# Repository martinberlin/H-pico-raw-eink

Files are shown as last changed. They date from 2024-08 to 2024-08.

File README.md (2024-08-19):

# H-pico-raw-eink

This is just a prototype PCB to test parallel eink signals with Raspberry PICO.

## Important To-Dos:

Find out if the pins selected for P-Mic signals and EINK signals behave correctly and are capable to do the job.

## Relevant datasheets

High voltages required by EPD P-Mic

https://www.ti.com/product/TPS65185

Eink signals described by Petteri Aimonen

http://essentialscrap.com/eink/waveforms.html

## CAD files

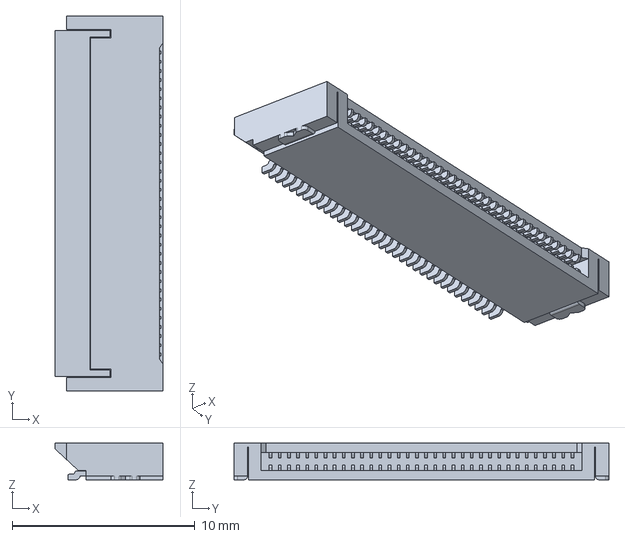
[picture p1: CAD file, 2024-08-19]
components/3d/X05A20H34G_EPD_connector.step
5.90 x 20.5 x 2.00 mm

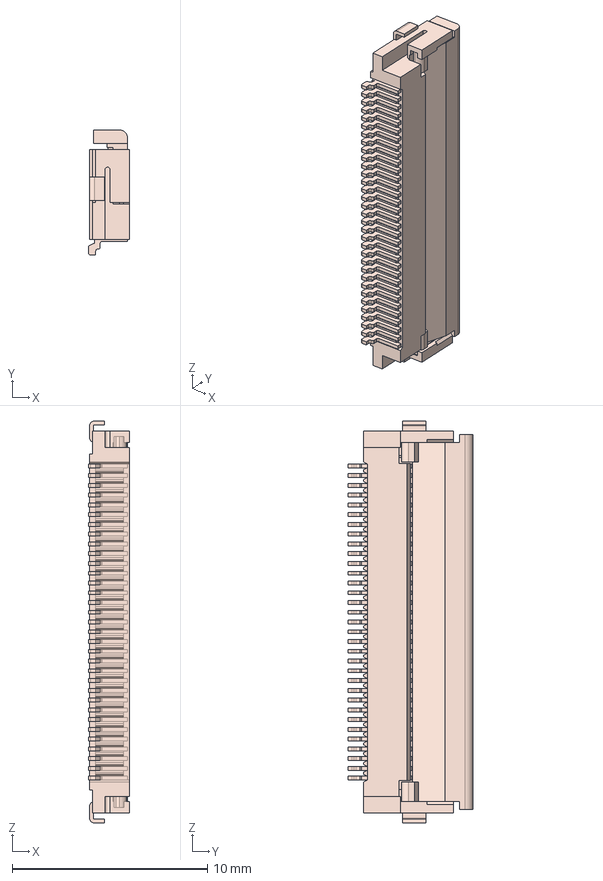
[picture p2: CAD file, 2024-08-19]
components/3d/FH12-33S-0.5SH.stp
2.10 x 6.40 x 20.6 mm

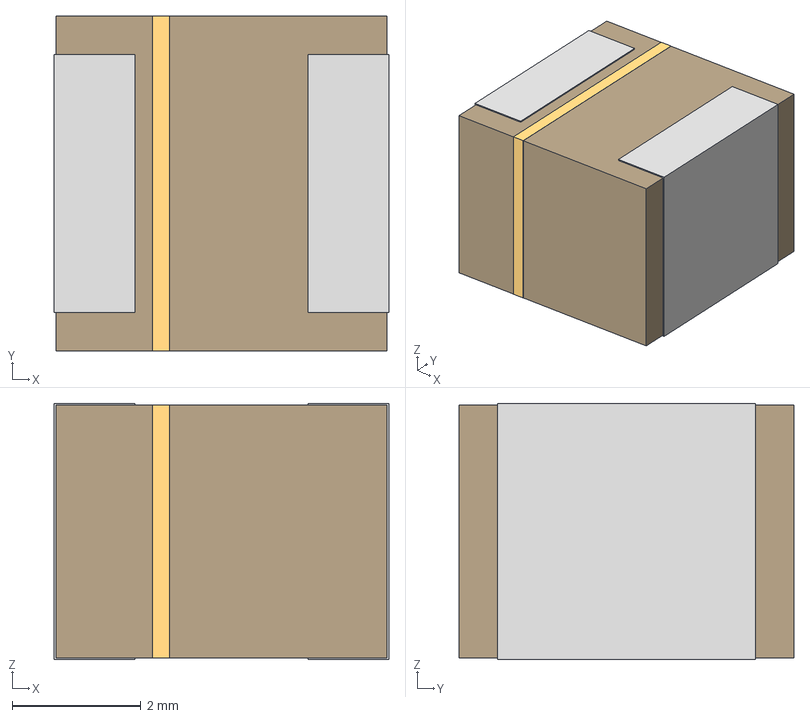
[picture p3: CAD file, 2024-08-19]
components/3d/IND_0S282MT_SNL.step
5.21 x 5.21 x 3.99 mm

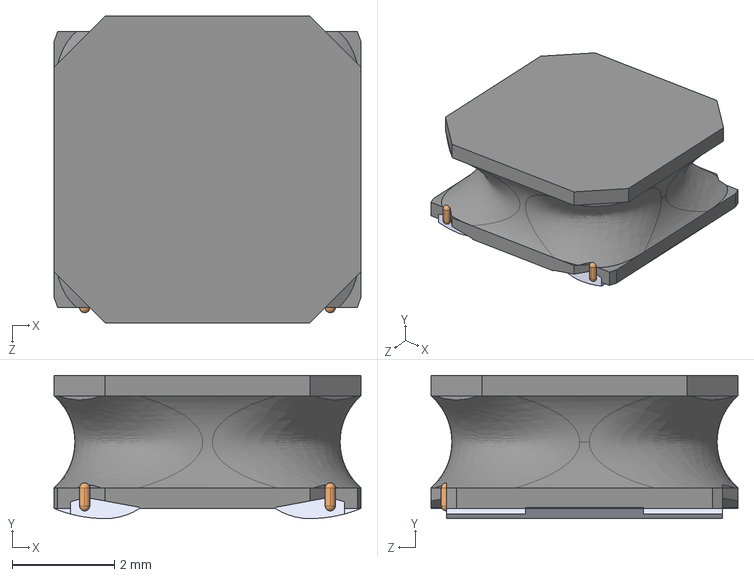
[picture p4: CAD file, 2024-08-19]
components/3d/L-40xx.STEP
6.00 x 2.80 x 6.00 mm

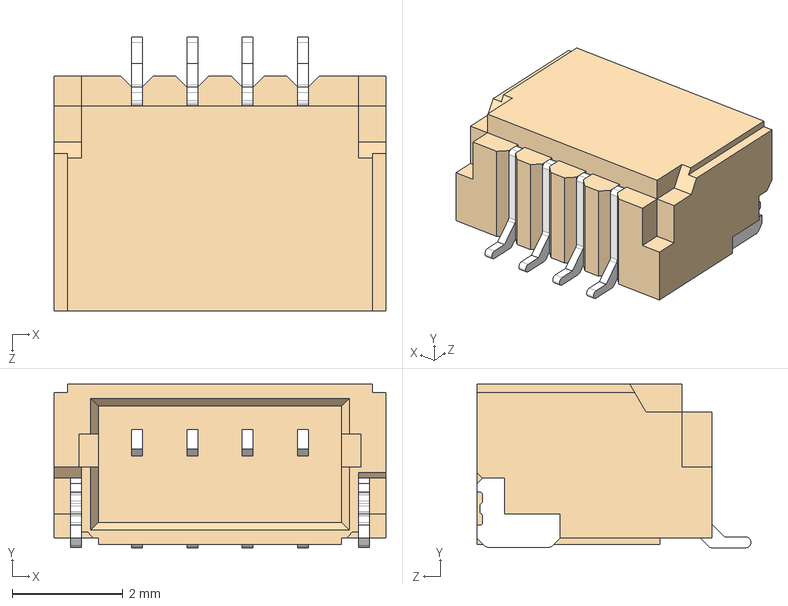
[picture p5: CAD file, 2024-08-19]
components/3d/QWIIC_SM04B-SRSS-TB_LF__SN_.stp
6.00 x 2.96 x 4.95 mm

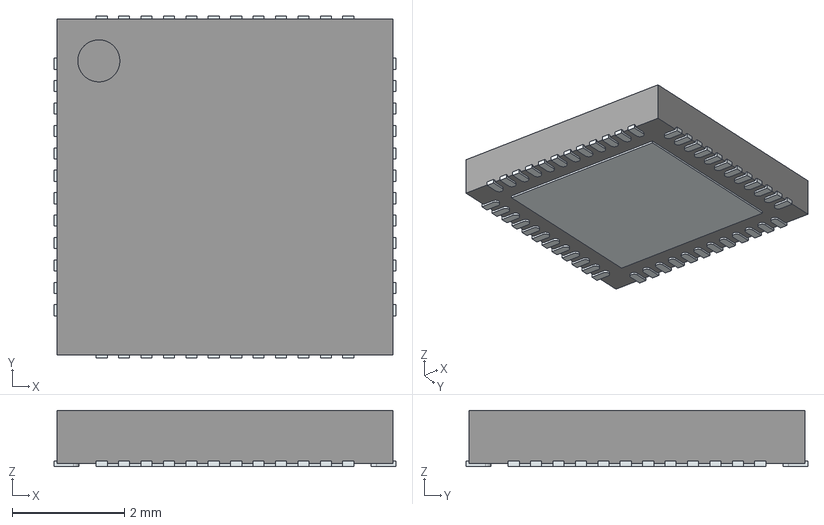
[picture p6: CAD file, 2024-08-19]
components/3d/TPS651851RSLR.step
6.10 x 6.10 x 1.00 mm
ThermalPin
PinsArrayLR
PinsArrayTB

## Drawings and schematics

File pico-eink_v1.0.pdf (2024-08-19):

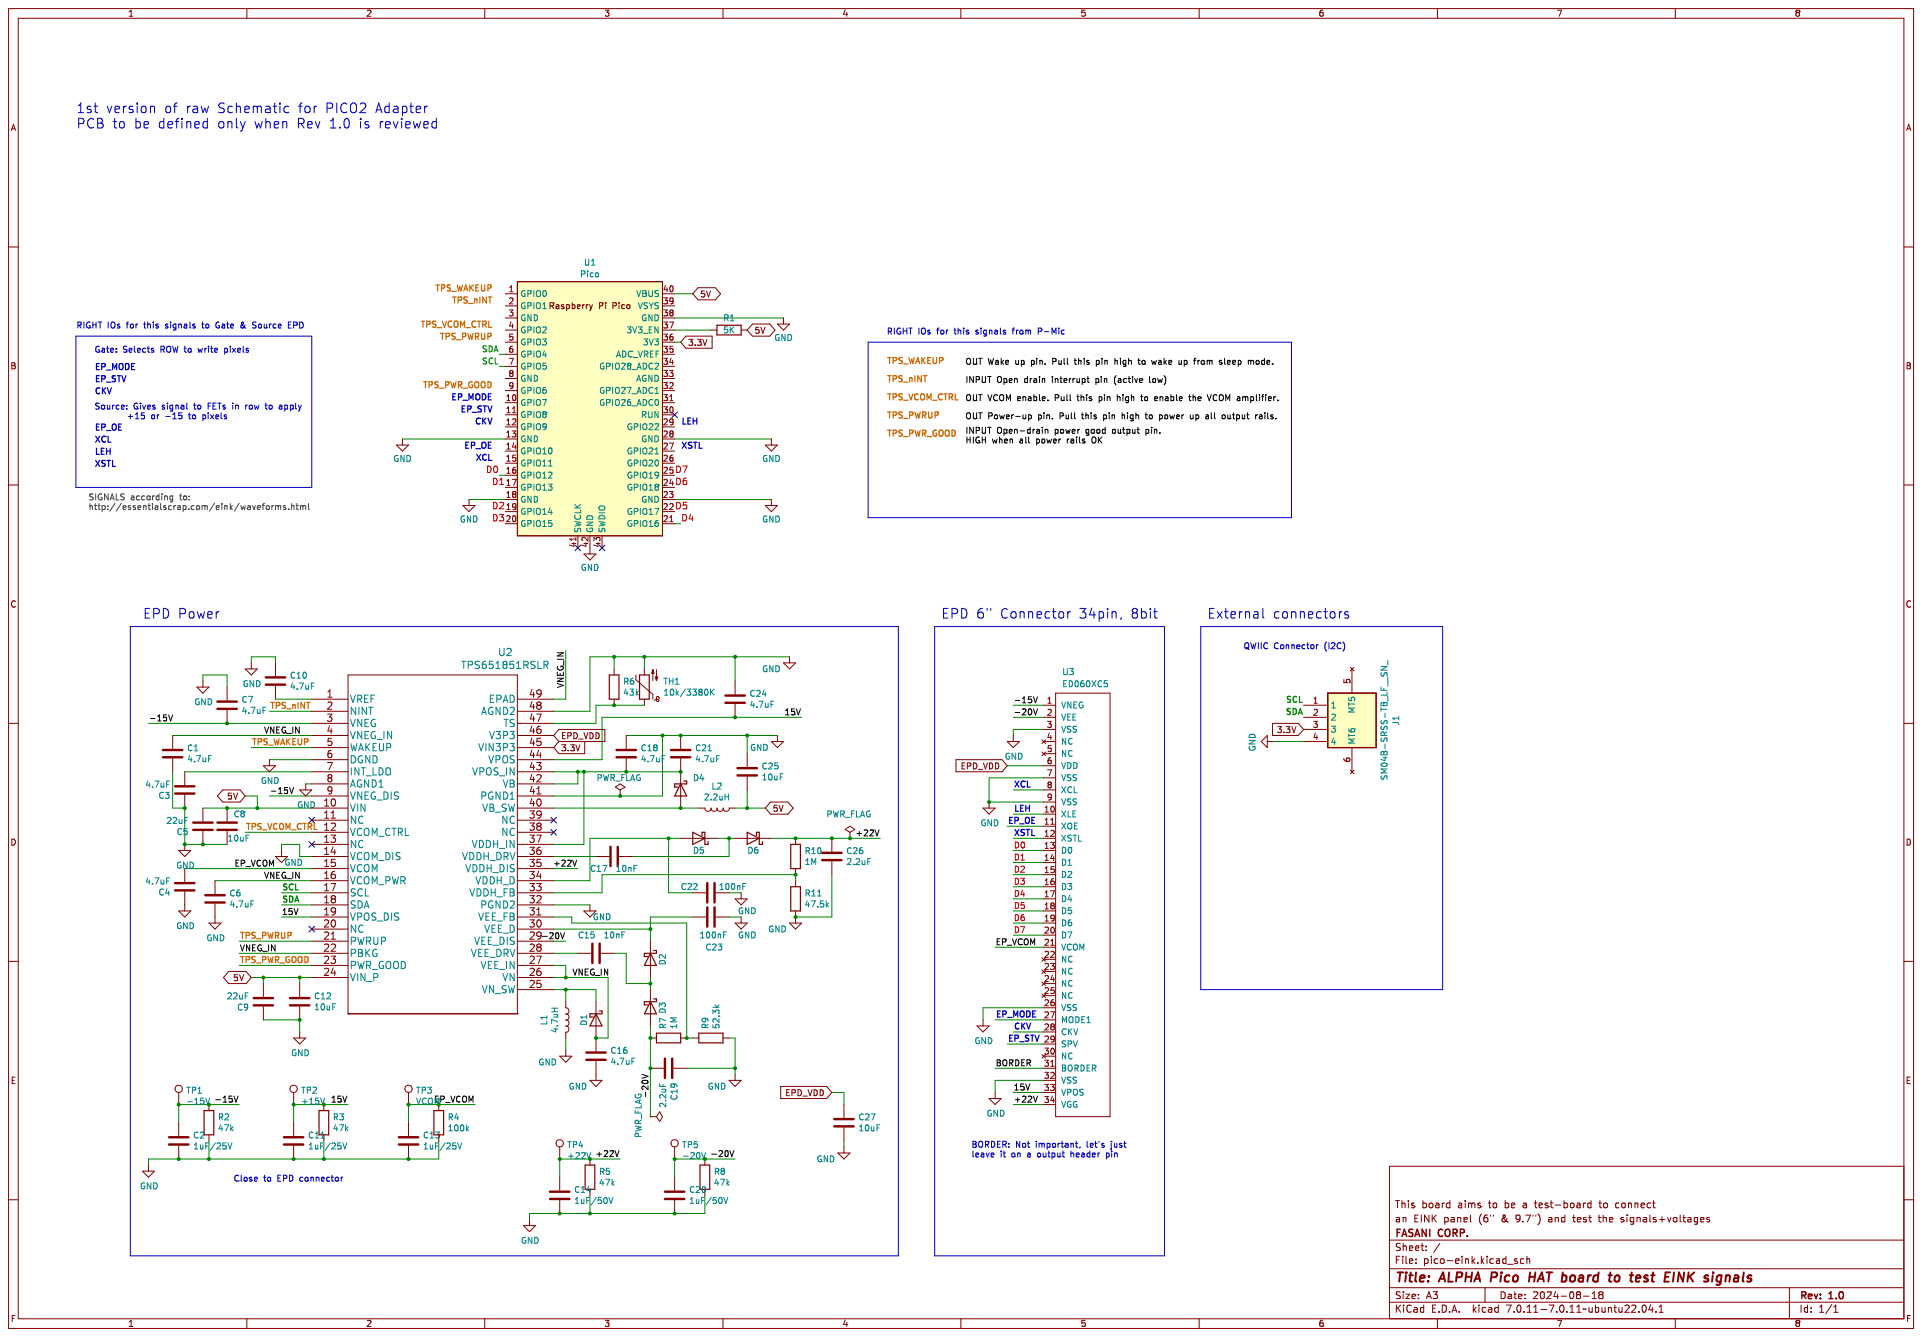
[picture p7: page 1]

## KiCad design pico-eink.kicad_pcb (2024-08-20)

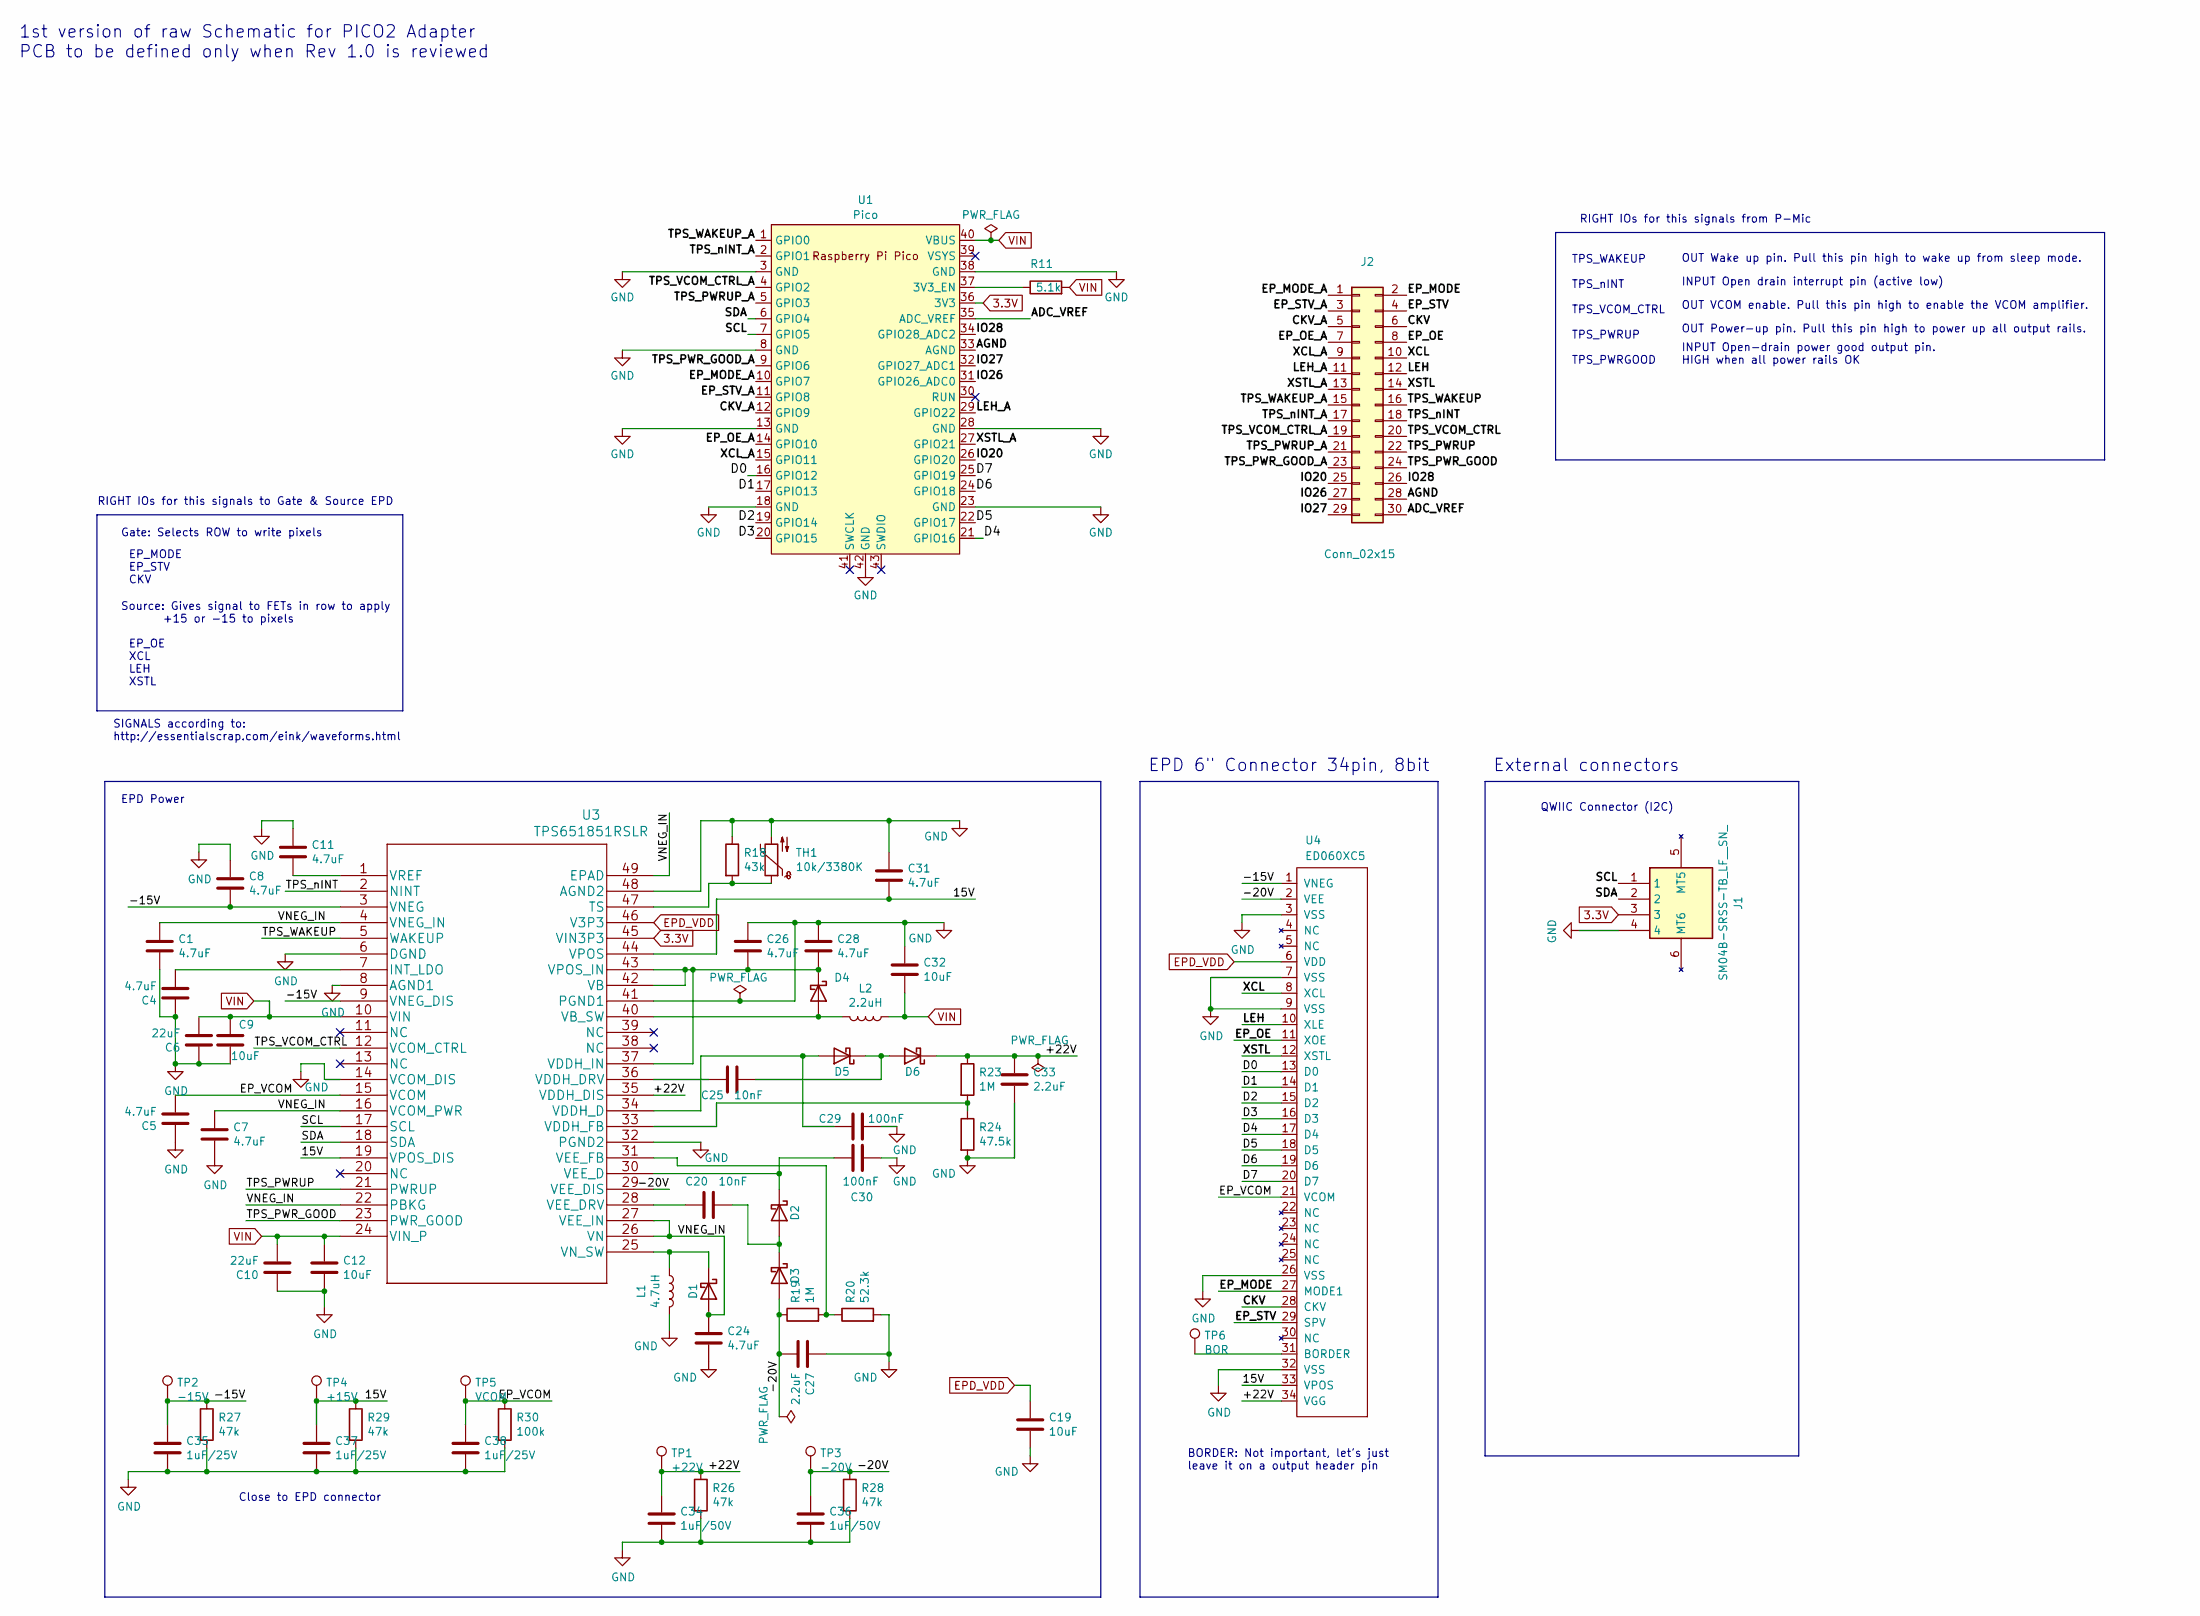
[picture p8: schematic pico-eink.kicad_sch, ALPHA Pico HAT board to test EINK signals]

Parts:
C1, C4, C5, C7, C8, C11, C24, C26, C28, C31: 4.7uF; C_0805_2012Metric; LCSC C1779
C6, C10: 22uF; C_0805_2012Metric; LCSC C45783
C9, C12, C19, C32: 10uF; C_0805_2012Metric; LCSC C15850
C20, C25: 10nF; C_0805_2012Metric; LCSC C1710
C27, C33: 2.2uF; C_0805_2012Metric; LCSC C49217
C29, C30: 100nF; C_0805_2012Metric; LCSC C49678
C34, C36: 1uF/50V; C_1206_3216Metric; LCSC C1848
C35, C37, C38: 1uF/25V; C_0805_2012Metric; LCSC C28323
D1, D2, D3, D4, D5, D6: MBR0540; D_SOD-123; LCSC C21353
J1: SM04B-SRSS-TB_LF__SN_; QWIIC_SM04B-SRSS-TB_LFSN_; Manufacturer_Part_Number SM04B-SRSS-TB(LF)(SN); LCSC C160404
J2: Conn_02x15; PinHeader_2x15_P2.54mm_Vertical
L1: 4.7uH; L_Taiyo-Yuden_NR-50xx_HandSoldering; LCSC C222947
L2: 2.2uH; L_Taiyo-Yuden_NR-40xx_HandSoldering; LCSC C92959
R11: 5.1k; R_0603_1608Metric; LCSC C23186
R18: 43k; R_0603_1608Metric; LCSC C23172
R19, R23: 1M; R_0603_1608Metric; LCSC C22935
R20: 52.3k; R_0603_1608Metric; LCSC C23196
R24: 47.5k; R_0603_1608Metric; LCSC C25819
R26, R27, R28, R29: 47k; R_0603_1608Metric; LCSC C25819
R30: 100k; R_0603_1608Metric; LCSC C25803
TH1: 10k/3380K; R_0603_1608Metric; LCSC C76589
TP1: +22V; TestPoint_Pad_D2.5mm
TP2: -15V; TestPoint_Pad_D2.5mm
TP3: -20V; TestPoint_Pad_D2.5mm
TP4: +15V; TestPoint_Pad_D2.5mm
TP5: VCOM; TestPoint_Pad_D2.5mm
TP6: BOR; TestPoint_Pad_D2.5mm
U1: Pico; RPi_Pico_SMD_TH
U3: TPS651851RSLR; LCSC C139292
U4: ED060XC5; X05A20H34G; LCSC C528053

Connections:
3.3V: J1.3, U1.36 (3V3), U3.45 (VIN3P3)
/15V: C31.2, C37.1, R29.1, TP4.1, U3.19 (VPOS_DIS), U3.44 (VPOS), U4.33 (VPOS)
/+22V: C33.1, C34.1, D6.1 (K), R23.1, R26.1, TP1.1, U3.35 (VDDH_DIS), U4.34 (VGG)
/-15V: C8.2, C35.1, R27.1, TP2.1, U3.3 (VNEG), U3.9 (VNEG_DIS), U4.1 (VNEG)
/-20V: C27.2, C36.1, D3.2 (A), R19.1, R28.1, TP3.1, U3.29 (VEE_DIS), U4.2 (VEE)
/ADC_VREF: J2.30, U1.35 (ADC_VREF)
/AGND: J2.28, U1.33 (AGND)
/CKV: J2.6, U4.28 (CKV)
/CKV_A: J2.5, U1.12 (GPIO9)
/D0: U1.16 (GPIO12), U4.13 (D0)
/D1: U1.17 (GPIO13), U4.14 (D1)
/D2: U1.19 (GPIO14), U4.15 (D2)
/D3: U1.20 (GPIO15), U4.16 (D3)
/D4: U1.21 (GPIO16), U4.17 (D4)
/D5: U1.22 (GPIO17), U4.18 (D5)
/D6: U1.24 (GPIO18), U4.19 (D6)
/D7: U1.25 (GPIO19), U4.20 (D7)
/EP_MODE: J2.2, U4.27 (MODE1)
/EP_MODE_A: J2.1, U1.10 (GPIO7)
/EP_OE: J2.8, U4.11 (XOE)
/EP_OE_A: J2.7, U1.14 (GPIO10)
/EP_STV: J2.4, U4.29 (SPV)
/EP_STV_A: J2.3, U1.11 (GPIO8)
/EP_VCOM: C5.2, C38.1, R30.1, TP5.1, U3.15 (VCOM), U4.21 (VCOM)
/IO20: J2.25, U1.26 (GPIO20)
/IO26: J2.27, U1.31 (GPIO26_ADC0)
/IO27: J2.29, U1.32 (GPIO27_ADC1)
/IO28: J2.26, U1.34 (GPIO28_ADC2)
/LEH: J2.12, U4.10 (XLE)
/LEH_A: J2.11, U1.29 (GPIO22)
/SCL: J1.1, U1.7 (GPIO5), U3.17 (SCL)
/SDA: J1.2, U1.6 (GPIO4), U3.18 (SDA)
/TPS_PWRUP: J2.22, U3.21 (PWRUP)
/TPS_PWRUP_A: J2.21, U1.5 (GPIO3)
/TPS_PWR_GOOD: J2.24, U3.23 (PWR_GOOD)
/TPS_PWR_GOOD_A: J2.23, U1.9 (GPIO6)
/TPS_VCOM_CTRL: J2.20, U3.12 (VCOM_CTRL)
/TPS_VCOM_CTRL_A: J2.19, U1.4 (GPIO2)
/TPS_WAKEUP: J2.16, U3.5 (WAKEUP)
/TPS_WAKEUP_A: J2.15, U1.1 (GPIO0)
/TPS_nINT: J2.18, U3.2 (NINT)
/TPS_nINT_A: J2.17, U1.2 (GPIO1)
/VNEG_IN: C1.1, C7.1, C24.1, D1.2 (A), U3.4 (VNEG_IN), U3.16 (VCOM_PWR), U3.22 (PBKG), U3.26 (VN), U3.27 (VEE_IN), U3.49 (EPAD)
/XCL: J2.10, U4.8 (XCL)
/XCL_A: J2.9, U1.15 (GPIO11)
/XSTL: J2.14, U4.12 (XSTL)
/XSTL_A: J2.13, U1.27 (GPIO21)
EPD_VDD: C19.1, U3.46 (V3P3), U4.6 (VDD)
GND: C1.2, C4.1, C5.1, C6.1, C7.2, C8.1, C9.2, C10.1, C11.1, C12.2, C19.2, C24.2, C26.1, C27.1, C28.1, C29.1, C30.2, C31.1, C32.1, C33.2, C34.2, C35.2, C36.2, C37.2, C38.2, J1.4, L1.2, R18.1, R20.2, R24.2, R26.2, R27.2, R28.2, R29.2, R30.2, TH1.2, U1.3 (GND), U1.8 (GND), U1.13 (GND), U1.18 (GND), U1.23 (GND), U1.28 (GND), U1.38 (GND), U1.42 (GND), U3.6 (DGND), U3.8 (AGND1), U3.14 (VCOM_DIS), U3.32 (PGND2), U3.41 (PGND1), U3.48 (AGND2), U4.3 (VSS), U4.7 (VSS), U4.9 (VSS), U4.26 (VSS), U4.32 (VSS)
unnamed: D1.1 (K), L1.1, U3.25 (VN_SW)
unnamed: C20.1, D2.2 (A), D3.1 (K)
unnamed: C30.1, D2.1 (K), U3.30 (VEE_D)
unnamed: D4.2 (A), L2.2, U3.40 (VB_SW)
unnamed: C26.2, C28.2, D4.1 (K), U3.37 (VDDH_IN), U3.42 (VB), U3.43 (VPOS_IN)
unnamed: C29.2, D5.2 (A), U3.34 (VDDH_D)
unnamed: C25.1, D5.1 (K), D6.2 (A)
unnamed: R11.1, U1.37 (3V3_EN)
unnamed: C4.2, U3.7 (INT_LDO)
unnamed: R18.2, TH1.1, U3.47 (TS)
unnamed: C25.2, U3.36 (VDDH_DRV)
unnamed: R23.2, R24.1, U3.33 (VDDH_FB)
unnamed: C20.2, U3.28 (VEE_DRV)
unnamed: R19.2, R20.1, U3.31 (VEE_FB)
unnamed: C11.2, U3.1 (VREF)
unnamed: TP6.1, U4.31 (BORDER)
VIN: C6.2, C9.1, C10.2, C12.1, C32.2, L2.1, R11.2, U1.40 (VBUS), U3.10 (VIN), U3.24 (VIN_P)

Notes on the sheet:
BORDER: Not important, let's just leave it on a output header pin
Gate: Selects ROW to write pixels
Close to EPD connector
TPS_WAKEUP TPS_nINT TPS_VCOM_CTRL TPS_PWRUP TPS_PWRGOOD
EPD 6" Connector 34pin, 8bit
INPUT Open drain interrupt pin (active low)
SIGNALS according to: http://essentialscrap.com/eink/waveforms.html
Source: Gives signal to FETs in row to apply +15 or -15 to pixels
RIGHT IOs for this signals to Gate & Source EPD
INPUT Open-drain power good output pin. HIGH when all power rails OK
OUT VCOM enable. Pull this pin high to enable the VCOM amplifier.
QWIIC Connector (I2C)
EPD Power
RIGHT IOs for this signals from P-Mic
OUT Wake up pin. Pull this pin high to wake up from sleep mode.
1st version of raw Schematic for PICO2 Adapter PCB to be defined only when Rev 1.0 is reviewed
EP_OE XCL LEH XSTL
EP_MODE EP_STV CKV
External connectors
OUT Power-up pin. Pull this pin high to power up all output rails.

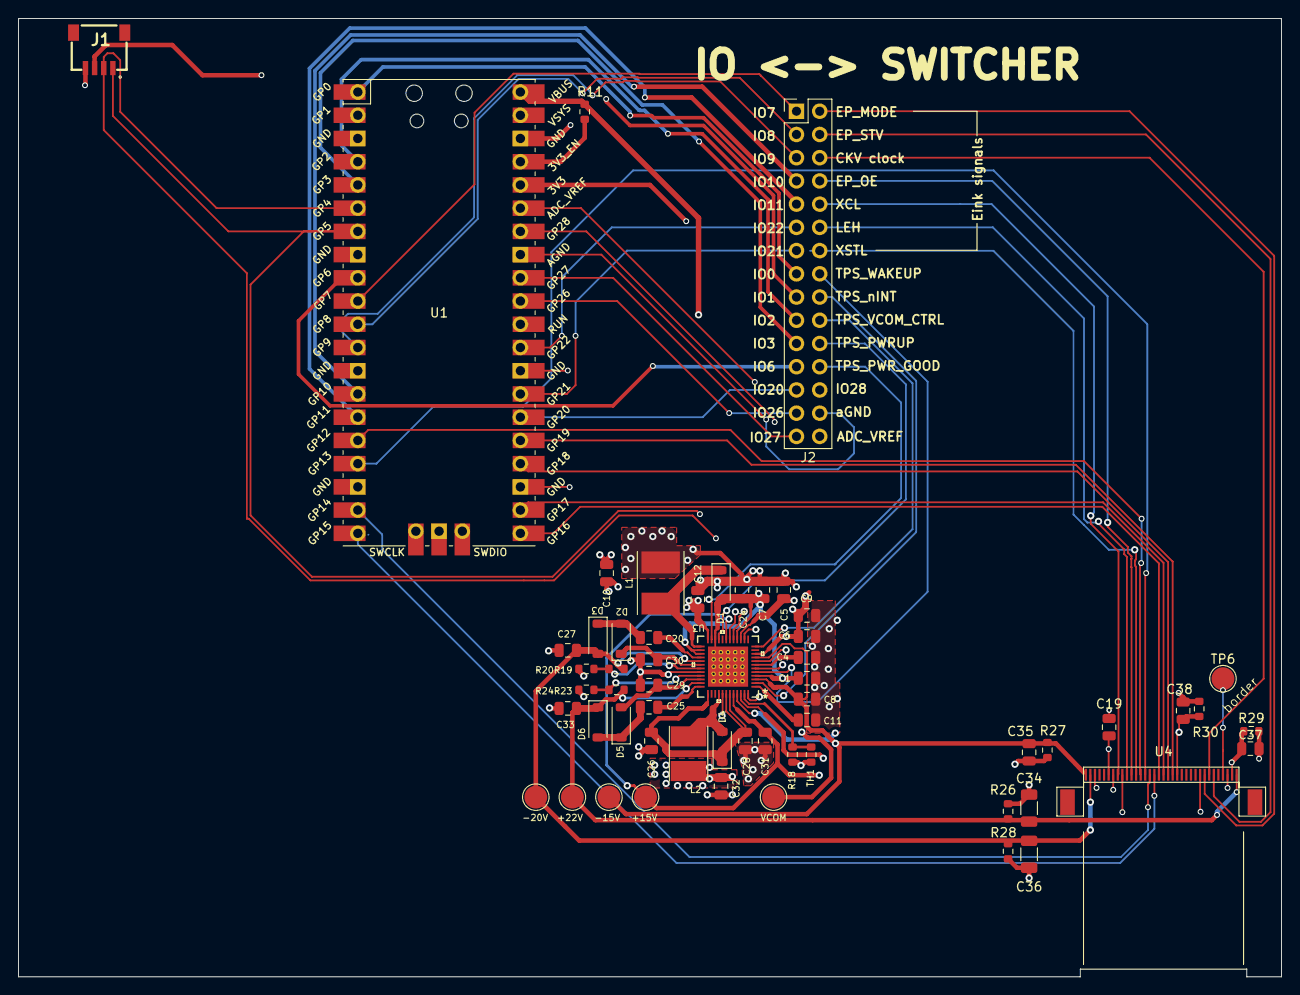
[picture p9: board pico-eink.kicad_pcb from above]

Board: 4 copper layers, 138.1 x 104.8 mm, 58 parts (0 on the bottom side), 66 nets.

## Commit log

2024-08-19 Add 1st raw schematic
2024-08-19 Add QWIIC
    [FH12-33S-0.5SH.stp, IND_0S282MT_SNL.step, L-40xx.STEP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]
2024-08-20 1st raw version, no DRM passed
    [pico-eink.kicad_pcb, pico-eink.kicad_sch]

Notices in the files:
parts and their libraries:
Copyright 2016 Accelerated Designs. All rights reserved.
